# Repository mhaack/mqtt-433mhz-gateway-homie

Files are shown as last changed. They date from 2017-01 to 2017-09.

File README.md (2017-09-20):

# 433Mhz <-> MQTT gateway with some extras  




The mqtt-433mhz-gateway-homie project is a simple bidirectional gateway to transmit and receive 433Mhz RF signals connected to MQTT. The
gateway is built with a cost-effective ESP8266 WiFi chip (I used a Wemos D1 mini, NodeMCU will do as well), simple 433Mhz RF modules and
an additional BMP085 sensor.

It enables to:
- receive MQTT data from a topic and send the 433Mhz signal
- receive 433Mhz signal from a traditional remote, optional map it to a channel and publish the data to a MQTT topic
- additional a simple temperature sensor can record the room temperature of the room where the gateway is installed

The software is based on [Homie](https://github.com/marvinroger/homie-esp8266) to enable an easy integration with home automation systems like [OpenHab](http://www.openhab.org).

## Hardware

- ESP8266 (Wemos D1 mini, Nodemcu)
- RF Receiver 433Mhz
- RF Transmitter 433MHz
- BMP085 or BMP180 sensor breakout

I got the RF modules form https://www.sparkfun.com, others will do as well. Additional I got some [Wemos Protoboards](https://www.wemos.cc/product/protoboard.html), an USB power supply with a very short cable
and an [enclosure](https://www.amazon.de/gp/product/B00PZYMLJ4) to keep all together.

### Building the circuit

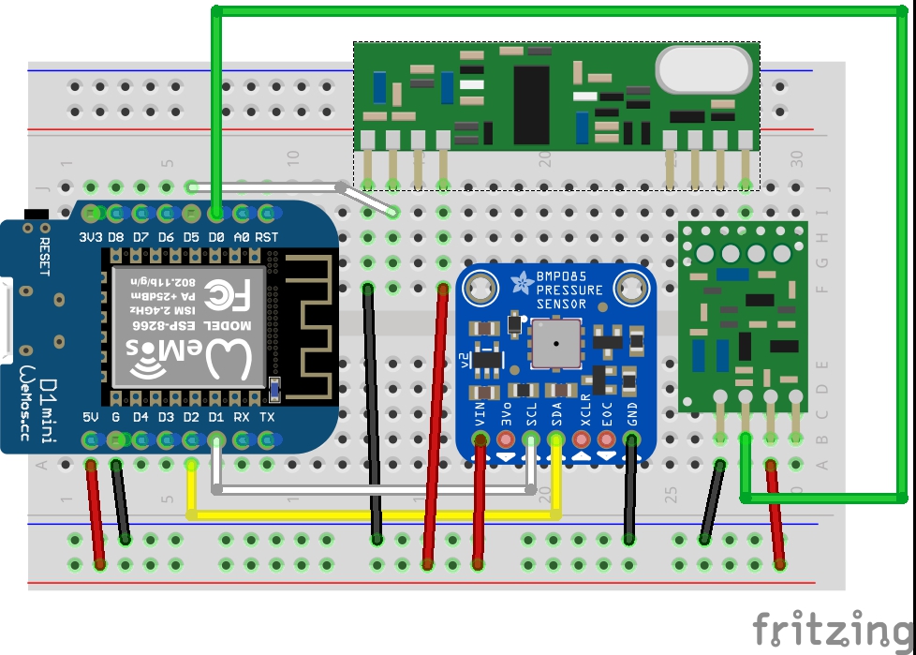
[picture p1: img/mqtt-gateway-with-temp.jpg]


Wemos D1 mini | BMP085 | RF Receiver | RF Transmitter
------------- | ------ | ----------- | --------------
5V            | VIN    | VIN         | VIN
GND           | GND    | GND         | GND
D0            |        |             | DATA
D1            | SCL    |             |
D2            | SDA    |             |
D5            |        | DATA        |

## Software

The following software libraries are used. When using PlatformIO all dependencies are resolved automatically.

- [Homie V2](https://github.com/marvinroger/homie-esp8266) (dev) including dependencies
- [RCSwitch](https://github.com/sui77/rc-switch)
- [Adafruit BMP085 Unified](https://github.com/adafruit/Adafruit_BMP085_Unified)
- [Adafruit Unified Sensor](https://github.com/adafruit/Adafruit_Sensor)
- Optionally PlatformIO environment for building the code

## MQTT
For a detailed documentation of the MQTT topics and commands used see [Homie documentation](https://homie-esp8266.readme.io/docs).

Sample gateway messages:

```
# sensor temperature reading
homie/mqtt-gateway-livingroom/temperature/degrees 23.70
```
Temperature value send form device.

```
# send RF command via MQTT & response
homie/mqtt-gateway-livingroom/MQTTto433/on/set 1394001
homie/mqtt-gateway-livingroom/MQTTto433/on 1394001
```
First line: MQTT command send from MQTT client or smart home solution. Translates into the code send by the RF transmitter.
Second line: Response from device after RF signal was send.

## Config

The following config parameters are available via MQTT message (see Homie documentation how to use):

Parameter           | Type        | Usage
------------------- | ----------- | -------
temperatureInterval | long        | temperature reading interval in seconds
temperatureOffset   | double      | temperature offset (-/+) to correct the sensor reading, for example if used in enclosure box
channels            | const char* | mapping of 433MHz signals to mqtt channels, useful if used with OpenHab

All configs can be set during the init procedure of the module or via MQTT messages (see Homie specification).

Sample config:

    {
        "settings": {
            "channels": "o-1:[139400];o-2:[139707];o-3:[1398097,1398100];o-4:[139803];i-1:[44618];i-2:[44620];i-3:[44623];i-4:[44638];i-5:[44700];“,
            "temperatureOffset“: -2.4,
            "temperatureInterval": 300
        }
    }

## Credits

This project is was inspired by 1 Technophile's [433toMQTTto433](https://1technophile.blogspot.de/2016/09/433tomqttto433-bidirectional-esp8266.html) solution.

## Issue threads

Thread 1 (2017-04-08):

Problem with sending data to ESP8266

animavitis, 2017-04-08:
Hi,

I have very stupid problem and want to for help.
Can u send me what need  to be send to ESP to trigger rfSwitchNode  (TOPIC & MESSAGE from MQTT to trigger RF emiter on ESP8266)?

thx for help:)

mhaack, 2017-04-08:
I added some sample to the readme.

```
# send RF command via MQTT & response
homie/mqtt-gateway-livingroom/MQTTto433/on/set 1394001
homie/mqtt-gateway-livingroom/MQTTto433/on 1394001
```
First line: MQTT command send from MQTT client or smart home solution. Translates into the code send by the RF transmitter.
Second line: Response from device after RF signal was send.

For a detailed documentation of the MQTT topics and commands used see [Homie documentation](https://homie-esp8266.readme.io/docs).

Closed 2017-04-08.

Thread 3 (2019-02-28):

What are the channels and how to configure them?

Maddmax76, 2019-02-28:
Hi, what do you mean with channels? They look like the RF contact codes, is that it?
What should I do to configure contacts to open doors, pIRs and remote controls with 4 buttons?

does the name "o-N" indicate an array?

Could you give me some guidance on how to configure my sensors?

thanks a lot

mhaack, 2019-03-01:
See the example in readme. Channels are create the link between MQTT messages and RF codes, for example for a for button remote: `b-1:[139400];b-2:[139707];b-3:[1398097,1398100];b-4:[139503]`

This is a list with the following pattern: ` s1:[s2]`. Where:
* s1 = string used for the MQTT topic, you can use any string you like for example `b-1` for button one
* s2 = the RF code send or received, this can be a list for example of a cheap remote control sends not one unique code

A button press on button 1 (with sample above) will publish the RC code value on `homie/<device-name>/433toMQTT/channel-b-1`.

HTH

Maddmax76, 2019-03-01:
Hi Mark, thanks for your reply.
What I miss is physically like telling him that the object that transmits
only the radio-frequency code "524745" is a read-only code, which is the
entrance door and that when that code arrives, it means that the door is
open.
Is this a gateway thing or should I implement it on the HA system?
If it does the gateway, does it in OTA or do I need to send the
configuration string via a clinetMQTT?

Specifically of my door opening sensor, the string should be:
  Door-Entry: [524745]
and this should publish on
  homie / NodeMCU / 433toMQTT / Door-Entry /

A remote control with 4 buttons configure it with:
Remote Control: [124589,124578,124536,124568]
and this should publish on
homie / NodeMCU / 433toMQTT / Remote control /?

Thanks and sorry if I'm a bit slow to understand :-)

Maddmax76, 2019-03-01:
Excuse me, a configuration like the following is correct?

    "settings": {
        "RemoteControl": "Button-Engage:[139400];Button-Disengage:[139707];Button.Perimetric:[1398097];Button-Panic:[139803];“,
        "Door-Entry":"Active:[524745]",
         "Door-Kitchen":"Active:[524745]",
    }

mhaack, 2019-03-01:
Please have a look at the readme for the config example. Also see Home doc (https://homieiot.github.io/homie-esp8266/docs/2.0.0/configuration/json-configuration-file/)

It should look like ```
{
    "settings": {
        "channels": "Button-Engage:[139400];Button-Disengage:[139707];Button-Perimetric:[1398097];Button-Panic:[139803];Door-Entry":[524745];Door-Kitchen:[524745];“
    }
}```

Make sure to not put any line breaks or space into the config string. Also I recommend to use shorter names like `b-e` etc. since there is a limitation on the size of the entire `settings` object.

Maddmax76, 2019-03-01:
perfect, thank you very much, now it's much clearer.
In practice, the remote control is seen as 4 different push-button devices.

The long names I had given them to be able to clarify my uncertainties.

The configuration of the devices can be done via Web UI in the first boot phase of the gateway or does that phase only concern the configuration of the wifi and the mqtt broker?

If I can not do it via Web UI I have to:
  create a config.json file in the sketch data folder
  upload it to the SPIFFS file system using Tools> ESP8266 Sketch Data Upload?

Again I'm sorry if I'm stressful but I would like to avoid frying my LoLin NodeMcu!

Thanks

Maddmax76, 2019-03-01:
according to the indications of

https://homieiot.github.io/homie-esp8266/docs/2.0.0/configuration/json-configuration-file/

the file should be like this:

{
  "name": "433toMQTT-Gateway",
  "device_id": "NodeMCU_1",
  "device_stats_interval": 60,
  "wifi": {
    "ssid": "MySSID",
    "password": "MyPWD"
  },
  "mqtt": {
    "host": "MyBroker",
    "port": 1883,
    "base_topic": "devices/",
    "auth": true,
    "username": "MyUser",
    "password": "MyPassword"
  },
  "ota": {
    "enabled": true
  },
  { "settings": { "channels": "Button-Engage:[139400];Button-Disengage:[139707];Button-Perimetric:[1398097];Button-Panic:[139803];Door-Entry":[524745];Door-Kitchen:[524745];“ } }
}
but all without spaces and on a line?

mhaack, 2019-03-03:
The Home sample has the full config you must provide on the initial config. If you update config via MQTT you can also do partial updates and only send the settings.

Maddmax76, 2019-03-04:
Good morning.
I entered the configuration via OTA, if I understood correctly what to put in the configuration, in the end it was quite simple....

But unfortunately:

- the gateway integrates Homie 2.0.1, hopenHAP has the binding for Homie 3.x, when I create the thing it marks it as OFFLINE because it lacks $ state, is it a typical parameter of version 3?
java.lang.Exception: Did not receive mandatory topic topic: homie / gw01 / $ state

- feedback on the NodeMCU the same problem that reflected on the sketch of 1 Technophile 433toMQTTto433: it seems that it does not receive data from the radiofrequency.
The receiver mounted on an ArduinoNano with the RCSwitch library works, in fact I was assuming to use the nano as a 433toSerial gateway.
Assuming that the NodeMcu was having problems I tried to change sketches, I found another code that uses RCSwitch to analyze the RF signals, and it works.
As you load your code or that of 1 Technophile the nodemcu part, connects to the wifi, connects to the broker mqtt, sends the keepalive signals and waits for signals, but receives nothing, even trying to change the pin where I connect the RF receiver

Do you have any idea?

mhaack, 2019-03-05:
https://github.com/homieiot/homie-esp8266 does not support Homie V3 - yet. That is still in development. So auto discovery does not work.

Maddmax76, 2019-03-05:
It's a pity, I'll wait impatiently for the new version then.
Thanks a lot!

mhaack, 2019-03-05:
You don't have to. It works with OpenHab as well, only no discovery but you can configure it in OpenHab manually.
Release of Homie impl. was not that often in the past, so I guess you will have to wait a while until that is implemented. Also this might need me to change the code of the mqtt-433mhz-gateway-homie to adapt. That said it will take time, I would not wait.

Maddmax76, 2019-03-05:
humm, is there somewhere explained how to create Button-like objects on openHab that read my channels?

Maddmax76, 2019-03-05:
apart from the fact that I must first make it work .... I do not know why but the version of RCSwitch that is in band with the gateway code does not work with my nodemcu, now I'm trying with the test sketch ReceiveDemo_Simple, but it does not go !

mhaack, 2019-03-05:
You can ask that on https://community.openhab.org but that should be possible, at the end it is only about sending or receiving MQTT commands in OH.

Maddmax76, 2019-03-05:
ok, thanks, Bye!

Maddmax76, 2019-03-07:
hello, I solved the problem of reception, in practice the nodeMcu wants pin 13 (D7) to receive the RF. Done that works everything beautifully. The RF signals were read and transformed into MQTT messages that I read with HoenHAB.
The doubt is that in the configuration of the gateway I have set only one channel, the channel is used to create a mqtt topic where the values of the received RF signals are written.
Can I create more channels to get a topic for every RF device I use? And can I do it using the mqtt commands? Does it make sense or does not it suit?

Thanks bye!

Maddmax76, 2019-03-07:
P.S. is there a way to download from the gateway the configuration file to be modified with a pc and then upload to the gateway with curl?

Thank you

mhaack, 2019-03-07:
> Can I create more channels to get a topic for every RF device I use?
Yes same way like channels for buttons they work in both ways.

> And can I do it using the mqtt commands?
Yes, see Homie doc. But it is always updating the entire settings only.

mhaack, 2019-03-07:
> P.S. is there a way to download from the gateway the configuration file to be modified with a pc and then upload to the gateway with curl?

You can do this using MQTT client. The gateway publishes the config during start. It is also logged to the console if you connect it via USB. A real download does not exist. Also CURL upload not only via MQTT.

Maddmax76, 2019-03-08:
hello Markus, good morning.

I took a look at the configuration printed via the console:

```
💡 Firmware mqtt-gateway-livingroom (1.0.0)
🔌 Booting into normal mode 🔌
{} Stored configuration
  • Hardware device ID: a020a6251b5a
  • Device ID: gw01
  • Name: gwp1
  • Device Stats Interval: 60 sec
  • Wi-Fi:
    ◦ SSID: not shown
    ◦ Password not shown
  • MQTT:
    ◦ Host: 192.168.1.17
    ◦ Port: 1883
    ◦ Base topic: homie/
    ◦ Auth? yes
    ◦ Username: not shown
    ◦ Password not shown
  • OTA:
    ◦ Enabled? yes
  • Custom settings:
    ◦ channels: A:[407052];B:[86292];C:[12663];D:[253233];E:[426330];F:[145665];G:[524745];H1:[429246];H2:[429228];H3:[429222];H4:[429220];I1:[102249];I2:[102231];I3:[102225];I4:[102223];L1:[102249];L2:[102231];L4:[102223];M1:[311013];M2:[310968];M3:[310962];M4:[310960]; (set)
↕ Attempting to connect to Wi-Fi...

```
ho dato anche un'occhiata alla configurazione di Homie:

https://homieiot.github.io/homie-esp8266/docs/2.0.0/configuration/json-configuration-file/

but I think I'm looking at the wrong documentation.

I still do not understand how to define objects.

How can I indicate that A is a sensor, which must have its own topic and that when I receive a radio signal that reads 407052, homie must write in the PIPPO topic the value ON?

How to tell him instead that H is a remote control that sends 4 different radio stations: ON(429246), OFF(429228), PERIMETER(429222), PANIC(429220)?

I can not find any syntax to use or to report on how the logic of the program behaves.

Thanks, ciao!

mhaack, 2019-03-10:
Hello,

the config looks ok. The channels work in both ways sender & receiver. If ran RF signal is received the gateway will transform that into MQTT message. On your remote control, if you press `ON` you should get some MQTT message on channel `H1` like `homie/gwp1/channel-H1` with the message send by the remote.
Same applies for the sensor. If on `407052` a RF signal is received you get an MQTT message on `homie/gwp1/channel-A` with the sensor value.

Best is to test with some MQTT client like: `mosquitto_sub -h 192.168.1.17 -v -t '#'` - plus username and password and see which messages are received.

Markus

Maddmax76, 2019-03-10:
Hi Markus, thanks for the information.

This morning I completed the configuration using the published information as the gateway publishes and working on the openHAB rules.

Now I managed to get what I wanted, a system parallel to my alarm system that can give me information on what triggered the alarm at home.

I only have to complete the gateway with the RF transmitter in order to activate or deactivate the alarm.

Thanks again for the suggestions and the patience and congratulations for the excellent work done with the gateway.

mhaack, 2019-03-11:
👍 closing this issue then.

Closed 2019-03-11.

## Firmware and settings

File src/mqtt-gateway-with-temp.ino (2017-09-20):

#include <Adafruit_BMP085_U.h>
#include <Adafruit_Sensor.h>
#include <Homie.h>
#include <RCSwitch.h>
#include <Wire.h>

// temp sensor
Adafruit_BMP085_Unified bmp = Adafruit_BMP085_Unified(10085);
unsigned long lastTemperatureSent = 0;
const int DEFAULT_TEMPERATURE_INTERVAL = 10;
const double DEFAULT_TEMPERATURE_OFFSET = 0;

// homie nodes & settings
HomieNode temperatureNode("temperature", "temperature");
HomieNode rfSwitchNode("MQTTto433", "switch");
HomieNode rfReceiverNode("433toMQTT", "switch");
HomieSetting<long> temperatureIntervalSetting("temperatureInterval", "The temperature interval in seconds");
HomieSetting<double> temperatureOffsetSetting("temperatureOffset", "The temperature offset in degrees");
HomieSetting<const char *> channelMappingSetting("channels", "Mapping of 433MHz signals to mqtt channel.");

// RF Switch
RCSwitch mySwitch = RCSwitch();

void setupHandler() { temperatureNode.setProperty("unit").send("c"); }

void loopHandler() {
    if (millis() - lastTemperatureSent >= temperatureIntervalSetting.get() * 1000UL || lastTemperatureSent == 0) {
        float temperature = 0;
        sensors_event_t event;
        bmp.getEvent(&event);
        if (event.pressure) {
            Serial << "Pressure: " << event.pressure << " hPa" << endl;
            bmp.getTemperature(&temperature);
            Serial << "Temperature: " << temperature << " °C" << endl;
            temperature += temperatureOffsetSetting.get();
            Serial << "Temperature (after offset): " << temperature << " °C" << endl;
        } else {
            Serial << "Sensor error" << endl;
        }
        temperatureNode.setProperty("degrees").send(String(temperature));
        lastTemperatureSent = millis();
    }

    if (mySwitch.available()) {
        long data = mySwitch.getReceivedValue();
        mySwitch.resetAvailable();
        Serial << "Receiving 433Mhz > MQTT signal: " << data << endl;

        String currentCode = String(data);
        String channelId = getChannelByCode(currentCode);
        Serial << "Code: " << currentCode << " matched to channel " << channelId << endl;
        rfReceiverNode.setProperty("channel-" + channelId).send(currentCode);
    }
}

String getChannelByCode(const String &currentCode) {
    String mappingConfig = channelMappingSetting.get();
    String mapping = "";
    String codes = "";
    int lastIndex = 0;
    int lastCodeIndex = 0;

    for (int i = 0; i < mappingConfig.length(); i++) {
        if (mappingConfig.substring(i, i + 1) == ";") {
            mapping = mappingConfig.substring(lastIndex, i);
            // Serial << "mapping: " << mapping << endl;

            codes = mapping.substring(mapping.indexOf(':') + 2, mapping.length() - 1);
            for (int j = 0; j < codes.length(); j++) {
                if (codes.substring(j, j + 1) == ",") {
                    if (currentCode.indexOf(codes.substring(lastCodeIndex, j)) > -1) {
                        return mapping.substring(0, mapping.indexOf(':'));
                        ;
                    }
                    codes = codes.substring(j + 1, codes.length());
                }
            }
            if (currentCode.indexOf(codes) > -1) {
                return mapping.substring(0, mapping.indexOf(':'));
                ;
            }
            lastIndex = i + 1;
        }
    }
    return "0";
}

bool rfSwitchOnHandler(const HomieRange &range, const String &value) {
    long int data = 0;
    int pulseLength = 350;
    if (value.indexOf(',') > 0) {
        pulseLength = atoi(value.substring(0, value.indexOf(',')).c_str());
        data = atoi(value.substring(value.indexOf(',') + 1).c_str());
    } else {
        data = atoi(value.c_str());
    }
    Serial << "Receiving MQTT > 433Mhz signal: " << pulseLength << ":" << data << endl;

    mySwitch.setPulseLength(pulseLength);
    mySwitch.send(data, 24);
    rfSwitchNode.setProperty("on").send(String(data));
    return true;
}

void setup() {
    Serial.begin(115200);
    Serial << endl << endl;

    // init BMP sensor
    if (!bmp.begin()) {
        Serial << "Ooops, no BMP085 detected ... Check your wiring or I2C ADDR!" << endl;
        while (1)
            ;
    }

    // init RF library
    mySwitch.enableTransmit(D0);    // RF Transmitter is connected to Pin D2
    mySwitch.setRepeatTransmit(20); // increase transmit repeat to avoid lost of rf sendings
    mySwitch.enableReceive(D5);     // Receiver on pin D3

    // init Homie
    Homie_setFirmware("mqtt-gateway-livingroom", "1.0.0");
    Homie.setSetupFunction(setupHandler).setLoopFunction(loopHandler);
    Homie.disableResetTrigger();

    rfSwitchNode.advertise("on").settable(rfSwitchOnHandler);
    rfReceiverNode.advertise("channel-0");

    temperatureNode.advertise("unit");
    temperatureNode.advertise("degrees");
    temperatureIntervalSetting.setDefaultValue(DEFAULT_TEMPERATURE_INTERVAL);
    temperatureOffsetSetting.setDefaultValue(DEFAULT_TEMPERATURE_OFFSET);

    Homie.setup();
}

void loop() { Homie.loop(); }
